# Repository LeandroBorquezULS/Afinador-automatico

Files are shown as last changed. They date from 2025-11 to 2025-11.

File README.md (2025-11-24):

## Afinador Automático

Este proyecto es un **afinador automático** desarrollado con el objetivo principal de ofrecer una herramienta de fácil acceso y uso para músicos, estudiantes, y cualquier persona interesada en afinar instrumentos musicales de manera precisa y rápida.

## Objetivo

El objetivo de este código es brindar un afinador automático que cualquiera pueda utilizar, permitiendo la afinación de instrumentos musicales de forma sencilla, intuitiva y rápida, sin necesidad de conocimientos técnicos avanzados. La interfaz y la lógica han sido diseñadas para minimizar la complejidad y maximizar la accesibilidad.

## ¿Cómo funciona?

El proyecto combina **Python** (95.5%) y **C++** (4.5%) para aprovechar las ventajas de ambos lenguajes:

- **Python:** Se encarga mayormente del procesamiento de señales de audio, la interfaz de usuario y la lógica principal del afinador.
- **C++:** Se utiliza para funciones de procesamiento de audio que requieren alta eficiencia y velocidad, como la detección rápida de frecuencia fundamental.

El afinador recibe una señal de audio (por ejemplo, de un micrófono), procesa la señal para detectar la frecuencia fundamental con algoritmos avanzados, y muestra al usuario la nota detectada y qué tan cerca está de la afinación perfecta.

## Características principales

- **Fácil de usar:** Interfaz accesible y minimalista.
- **Automático:** No requiere ajustes manuales por parte del usuario.
- **Precisión:** Algoritmos robustos de análisis de frecuencia.
- **Multiplataforma:** Pensado para funcionar en diferentes sistemas operativos.
- **Código abierto:** Puedes revisar, modificar y mejorar el código libremente.

## Tecnologías utilizadas

- **Python**: Librerías para procesamiento de audio como `numpy`, `scipy`, y `sounddevice` o `pyaudio`.
- **C++**: Módulos optimizados integrados sobre Python para análisis eficiente de la señal.

## Instalación y uso

1. Clona/Descargar este repositorio:
2. Instala las librerias requeridas.
3. Ejecuta el script principal que se encuentra en "main" siguiendo las instrucciones del repositorio.

## Materiales
(estos son los materiales esenciales para su funcionamiento)
- Motor Paso a Paso 28BYJ-48, 5v
- Driver ULN2003
- ESP32 D1 mini

## Contribuciones

¡Cualquier mejora, sugerencia o reporte es bienvenido! Este proyecto busca crecer como una herramienta comunitaria de acceso abierto.

---

**Hecho por [Leandro Borquez-Cristián Contreras-Maximiliano Molina-Jose Barraza-Maximiliano Oyarse-Piero Araya]**
- Bajo el contexto de la aplicación de Series de Fourier, en el marco del ramo Matemáticas IV, impartido por el Doctor Eric Roberto Jeltsch Figueroa en la Universidad de La Serena.
- Proyecto enfocado en el acceso universal a herramientas musicales inteligentes.

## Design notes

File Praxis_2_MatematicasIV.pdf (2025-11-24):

# Afinador Automatico de Instrumentos de Cuerda ´

Leandro Borquez, Piero Araya, Cristian Contreras, Maximiliano Oyarce, Maximiliano Molina, Jos ´ | e Barraza ´
Universidad de La Serena Ingeniería en Computacion´
Abstract—Este documento presenta el diseno e implementaci ˜ | on´
de un afinador automatico para instrumentos de cuerda. El ´ sistema utiliza analisis espectral mediante series de Fourier ´ para detectar la frecuencia fundamental de cada cuerda y un
sistema mecatronico para ajustar autom ´ | aticamente la tensi ´ | on. Se ´
describe el modelado matematico, la implementaci ´ | on hardware ´
con Arduino/ESP32, y los algoritmos de procesamiento digital de senales. Los resultados demuestran la efectividad del sistema ˜ para afinar guitarras con precision comparable a afinadores ´ comerciales.
Index Terms—Afinador automatico, series de Fourier, proce- ´
samiento digital de senales, Arduino, control autom ˜ | atico, STEM. ´
I. INTRODUCCION´
A. Problema desencadenante

La afinacion manual de instrumentos de cuerda requiere ´ entrenamiento auditivo y puede ser imprecisa para musicos ´ principiantes. Ademas, en entornos profesionales se requiere ´
rapidez y precision. Un sistema autom ´ | atico resolver ´ | ía estos
problemas proporcionando afinacion precisa independiente- ´ mente de la habilidad del usuario.
B. Limitaciones del afinado manual

El afinado manual para los instrumentos de cuerda es la manera mas usual al momento de afinar un instrumento de ´ cuerda como lo sería una guitarra, pero este metodo tiene ´ varios inconvenientes tales como la falta de experiencia, la falta de exactitud ya sea por problemas auditivos o por lo mismo de la falta de experiencia musical, un instrumento de cuerda como lo es la guitarra no estaría afinada a la nota exacta y tambien se pueden producir ciertos inconvenientes ´ al momento de estar afinado, como lo es que se rompa una cuerda por estar demasiado tensa y ademas aunque se afine ´ el instrumento hay factores externos que hacen que varíe la afinacion a lo largo del tiempo por lo que se debe de ´ comprobar la afinacion peri ´ odicamente. ´

C. Propuesta

Entonces como equipo se decidio por desarrollar un sistema ´
automatico para la afinaci ´ | on de la mayor ´ | ía de instrumentos de
cuerda, con la capacidad de que se acople a la mayoría de clavijeros y que pueda ajustar automaticamente las clavijas ´
para la afinacion de estos instrumentos. Adem ´ | as, el proyecto ´
busca ser una solucion de bajo costo y accesible, priorizando ´
componentes economicos y un dise ´ | no simple que permita ˜
que cualquier musico, tanto principiante como experimentado, ´ pueda utilizarlo sin necesidad de equipos profesionales.

II. OBJETIVOS
A. Objetivo General
Disenar e implementar un sistema autom ˜ | atico para afinar ´
instrumentos de cuerda que combine procesamiento digital de
senales y control mecatr ˜ | onico. ´
B. Objetivos Específicos
- Aplicar series de Fourier para deteccion de frecuencia ´ fundamental en senales de audio ˜
- Disenar el sistema mecatr ˜ | onico para ajuste autom ´ | atico de ´
clavijas
- Implementar algoritmos de control PID para el ajuste fino de tension´
- Validar el sistema experimentalmente comparando con afinadores comerciales o aplicaciones moviles para afinar ´ instrumentos
- Desarrollar habilidades STEM integradas en el equipo

III. MARCO TEORICO ´

A. Teoría Musical y Afinacion´
En el sistema occidental el sonido musical se organiza en 12 alturas por octava. Frecuencias estandar (A4 = 440Hz) para ´ la nota La en la cuarta octava en la afinacion moderna. Los ´ intervalos se miden por ”cents”, un semitono son 100 cents. En la musica el sonido tiene 4 cualidades las cuales son ´
- Altura, cualidad que determina si un sonido es agudo o grave
- Duracion´ tiempo en el que se mantienen las vibraciones producidas por el sonido
- Intensidad la diferencia entre un sonido suave y un sonido fuerte
- Timbre, cualidad que depende de los armonicos y de la ´ intensidad de estos
B. Afinadores comerciales y profesionales
Un afinador es una herramienta electronica con la capacidad ´ de detectar las vibraciones del sonido de un instrumento y muestra si se debe de ajustar la nota, para que el instrumento
este afinado, este es el m ´ | etodo m ´ | as r ´ | apido y efectivo para ´
lograr una afinacion precisa, pero no siempre es accesible ´ un afinador de alta calidad a un bajo precio. Afinadores por sistema
- Afinador Estandar ´ Afinadores usados por la mayoría, que solo detectan las notas específicas de la afinacion´ predeterminada de un instrumento.
- Afinador Cromatico ´ Estos detectan las 12 notas de la escala musical independientemente del instrumento, usado por profesionales por su versatilidad y exactitud.

- Diapason´ | Produce una nota de referencia inmutable
generalmente la de 440 Hz, es el metodo m ´ | as cl ´ | asico ´
para afinar un instrumento.
Afinadores por formato

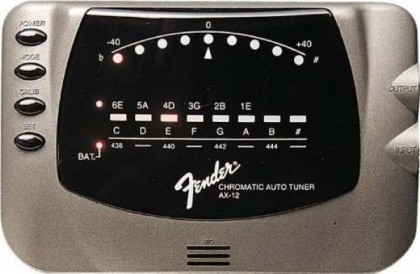
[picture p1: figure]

Fig. 1: Afinador Cromatico ´

Variaciones de los distintos afinadores
- Afinador de Pinza Estos se ajustan directamente al instrumento, leen las vibraciones directamente, lo que garantiza una afinacion precisa en ambientes ruidosos, ´
estos se ajustan a la clavijera o al mastil de un viol ´ | ín.
- Compacto Estos afinadores son para llevarlos en el bolsillo ideales para viajar con ellos, generalmente son del tipo cromatico ´ , con una entrada jack para guitarras electricas o bajos. ´
- Afinador de pedal Para guitarras y bajos electricos donde ´ se usa el pedal de efectos, permiten afinar directamente mientras se esta tocando, pudiendo activarlos y desacti- ´ varlos a voluntad.

IV. PROCESAMIENTO DIGITAL DE SENALES ˜

1) Series de Fourier:

f(x) = a0
2

+

X∞

n=1

(an cos(nπ
L
x) + bn sin(nπ
L
x)) | (1)
2) Transformada Rapida de Fourier (FFT): ´ | Algoritmo para
calculo eficiente del espectro de frecuencia con la FFT, de- ´ scomponiendo la senal de audio de la cuerda en sus compo- ˜ nentes de frecuencia, donde el pico de mayor amplitud es la frecuencia fundamental.
A. Percepcion del pitch ´

La frecuencia fundamental y armonicos, la frecuencia fun- ´ damental define la altura percibida de un sonido lo que sería su pitch, mientras que los armonicos son las diferentes ”distan- ´ cias” que se tienen para recorrer para cada nota, haciendo que
los armonicos sean los m ´ | ultiplos enteros de esta frecuencia ´
fundamental.
Por lo que se puede concluir que un sonido consta de su
frecuencia fundamental, seguido de los armonicos m ´ | ultiplos ´
de esta frecuencia fundamental.
B. Descomposicion espectral ´

Por medio de la FFT se va a descomponer el sonido de las cuerdas, mostrando su frecuencia fundamental y permitiendo compararla con la frecuencia de referencia de 440Hz.

C. Teoría de Control
Control PID para el sistema de ajuste de tension donde ´ el controlador automatico iterativo ajusta el motor en bucle ´ cerrado. Que calcula los pasos en funcion del error ´
u(t) = min
nmax

|cents|

cents − por − paso
(2)

El controlador proporcional-integral-derivativo o PID, se en-
cargara de decidir cu ´ | anto y en qu ´ | e sentido se debe de mover el ´
motor a paso a paso que tensa o afloja la cuerda y así alcanzar la frecuencia deseada para cada cuerda. Entonces la mision de ´
este controlador es la de traducir el error instantaneo en ´ | cents
en una cantidad entera de pasos del motor, lo que permite que:
1) Corrija la desviacion en un instante ´
2) Que no sobrepase los límites del clavijero.
V. FUNDAMENTOS TEORICOS ´
A. ¿Como se debe afinar una guitarra? ´
El estandar para la afinaci ´ | on de guitarras es de (mi-la-re- ´
sol-si-mi) donde la sexta cuerda corresponde a la nota Mi (E), la quinta en La (A), la cuarta en Re (D), la tercera en Sol (G), la segunda en Si (B) y la primera cuerda afinada tambien en ´ Mi (E). La frecuencia referencial mas com ´ un es la de 440Hz. ´
B. Temperamento igual
El temperamento igual divide la octava en 12 partes iguales, a los que se les conoce como semitonos. Un semitono sería el
espacio mas peque ´ | no entre las notas en el sistema occidental, ˜
donde cada semitono va a medir la distancia de 12√
2. Esta
distancia mínima permite calcular la frecuencia de todas las
notas con esta formula ´ | (

12√
2)n ∗ f, donde f sera la frecuencia ´ de la nota de referencia y n es el numero de semitonos que ´ se quiere subir a partir de la nota de referencia.
C. Cuerdas vibrantes
En una cuerda su vibracion ser ´ a una onda cuyo sonido ´ producido sera una frecuencia constante, las cuerdas vibrantes ´ son la base de los instrumentos de cuerda como la guitarra, el violín o el piano. Donde su funcionamiento sigue las leyes de Mersenne, que se podría resumir en estos tres principios
- Mas corta la cuerda, m ´ | as alta es la frecuencia del modo ´
fundamental o una cuerda mas corta produce una nota ´ mas aguda. ´
- Mas grande la tensi ´ | on, m ´ | as alta es la frecuencia fun- ´
damental o una cuerda mas tensa vibra m ´ | as r ´ | apido, ´
produciendo una nota mas aguda. ´
- Mas liviana la cuerda, m ´ | as alta es la frecuencia del modo ´
fundamental o entre mas liviana una cuerda m ´ | as aguda ´
es la nota que produce.
VI. DISENO DEL ˜ | SISTEMA
A. Arquitectura General
El sistema debe de
1) Capturar el audio del microfono ´
2) Procesar la senal y usar la FFT para encontrar la ˜ frecuencia fundamental

3) Comparar la frecuencia medida con la frecuencia objetivo de cada cuerda, con la tabla de frecuencia del temperamento igual
4) Controlar los motores para aumentar o disminuir la tension´
5) Iterar Repetir el proceso hasta que el instrumento esté afinado

Diagrama de la secuencia

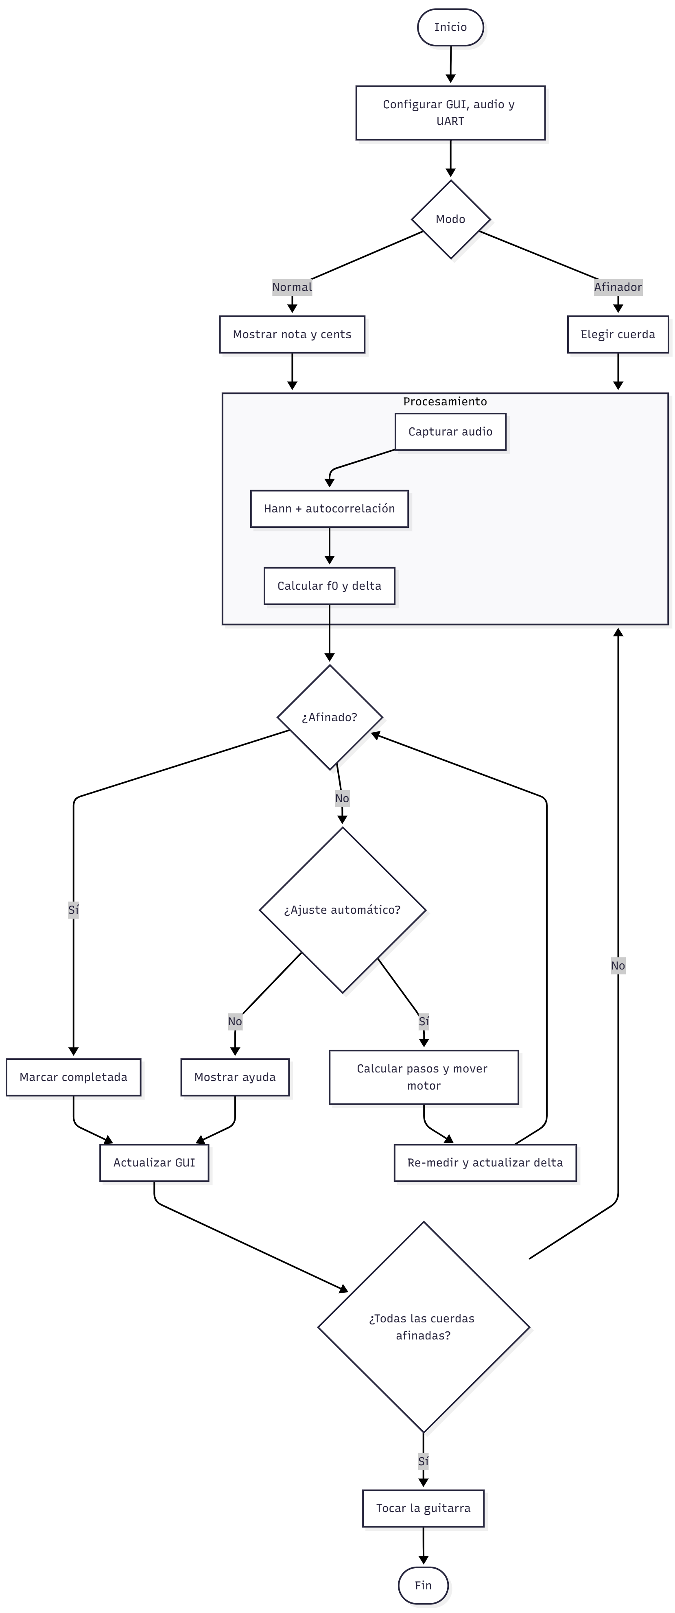
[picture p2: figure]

Fig. 2: Diagrama DFD

B. Modelado Matematico REVISAR ´
1) Modelo de la Cuerda: Ecuacion de onda para cuerdas ´ vibrantes:
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
2) Relacion Tensi ´ | on-Frecuencia: ´ | Ley de Mersenne. Esta
funcion convertir ´ | a el error ´ | δ en accion mec ´ | anica sin la ´
necesidad de medir el tiempo T, L, µ:

f =

1
2L

s
T
µ

(4)

La solucion de estas ecuaciones permite convertir el error ´ calculado en cents, en un numero discreto de pasos para el ´ motor calculando experimentalmente la ganancia.

VII. ESTADO DEL ARTE
Realizando un analisis de los afinadores digitales existentes, ´ así como de las aplicaciones moviles actuales, se observa que ´ el mercado ofrece una amplia variedad de herramientas para la
afinacion. Sin embargo, la gran mayor ´ | | ía de estos dispositivos
aun requiere que el usuario realice el ajuste manual del ´ instrumento. En contraste, los sistemas semiautomaticos y ´
automaticos de afinaci ´ | on representan solo una fracci ´ | on muy ´
pequena del mercado, convirti ˜ | endose en productos de nicho ´
debido a su alto costo, complejidad mecanica o falta de ´ accesibilidad.

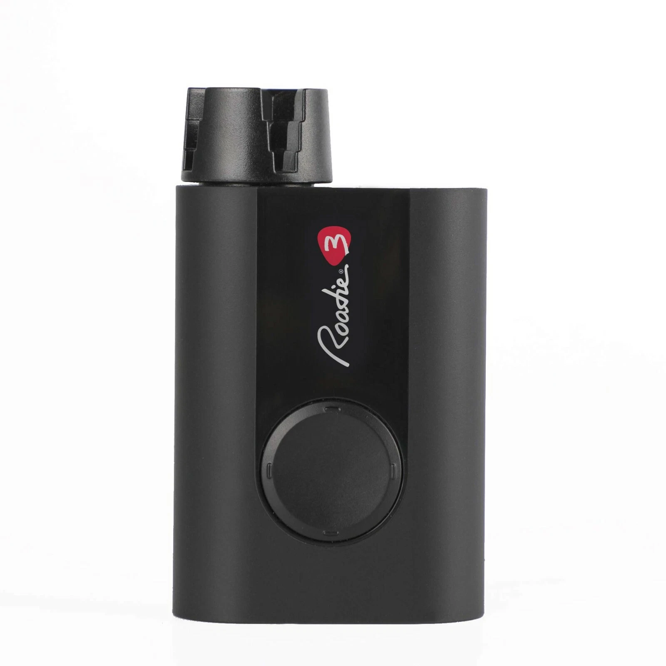
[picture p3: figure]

Fig. 3: Afinador automatico ´

Historicamente, el estudio de la afinaci ´ | on y del an ´ | alisis ´
de frecuencias comenzo a formalizarse a mediados del siglo ´ XX, cuando surgieron las primeras investigaciones en proce-
samiento digital de senales (DSP). Con la aparici ˜ | on de los ´
primeros computadores en la decada de 1960, se desarrollaron ´
las bases matematicas de la Transformada R ´ | apida de Fourier ´
(FFT), introducida por Cooley y Tukey en 1965, lo que per-
mitio analizar se ´ | nales musicales con mucha mayor eficiencia. ˜
Estas herramientas fueron inicialmente utilizadas para fines militares y de telecomunicaciones, como analisis espectral de ´ senales de radar, sonar y comunicaciones de radio. Con el ˜ tiempo, la tecnología migro hacia aplicaciones recreativas, ´ educativas y artísticas, impulsando su uso en el estudio del sonido y la musica. ´
Desde la decada de 1980, el procesamiento de audio digital ´
comenzo a integrarse en sintetizadores, afinadores electr ´ | onicos ´
de mano y equipos de grabacion profesional. A inicios de ´ los anos 2000, el avance de los microcontroladores y sen- ˜
sores mas econ ´ | omicos permiti ´ | o que proyectos acad ´ | emicos y ´
experimentales exploraran la afinacion autom ´ | atica mediante ´
motores de precision y algoritmos que detectan la frecuencia ´ fundamental de cuerdas en vibracion. Diversas investigaciones ´
han empleado tecnicas basadas en FFT, autocorrelaci ´ | on, filtros ´
digitales y analisis espectral avanzado para lograr una esti- ´ macion precisa del tono musical. ´
En el ambito acad ´ | emico, se han desarrollado numerosos ´
trabajos enfocados en la afinacion digital y el control autom- ´ atizado de instrumentos musicales. Algunos estudios abordan algoritmos de deteccion de pitch robustos al ruido, mientras ´ que otros se concentran en la construccion de sistemas elec- ´ tromecanicos capaces de ajustar tensiones de cuerdas. Incluso ´

existen proyectos que implementan sistemas completos de
afinacion autom ´ | atica, dise ´ | nando actuadores controlados por ˜
microcontroladores para manipular clavijas de instrumentos de cuerda de manera autonoma. ´

Con el crecimiento de la computacion embebida y el ´ acceso a plataformas como Arduino, ESP32 y Raspberry Pi, la investigacion reciente se ha orientado hacia sistemas ´
mas compactos, energ ´ | eticamente eficientes y accesibles para ´
el publico general. Esto ha permitido desarrollar prototipos ´
economicos y port ´ | atiles con capacidades que antes solo se ´
encontraban en dispositivos profesionales de alto costo.

En conclusion, aunque existe un cuerpo importante de ´
estudios y prototipos relacionados con la afinacion autom ´ | atica, ´
la mayoría no se ha traducido en productos comerciales ampliamente accesibles. Esto refuerza la necesidad de soluciones de bajo costo, simples de usar y capaces de adaptarse a distintos instrumentos, especialmente en contextos educativos, recreativos y artísticos.

VIII. IMPLEMENTACION´

A. Hardware
- Microcontrolador: Arduino/ESP32
- Sensor: Microfono ´
- Actuadores: motores paso a paso
- Mecanismo: Adaptador para clavijas

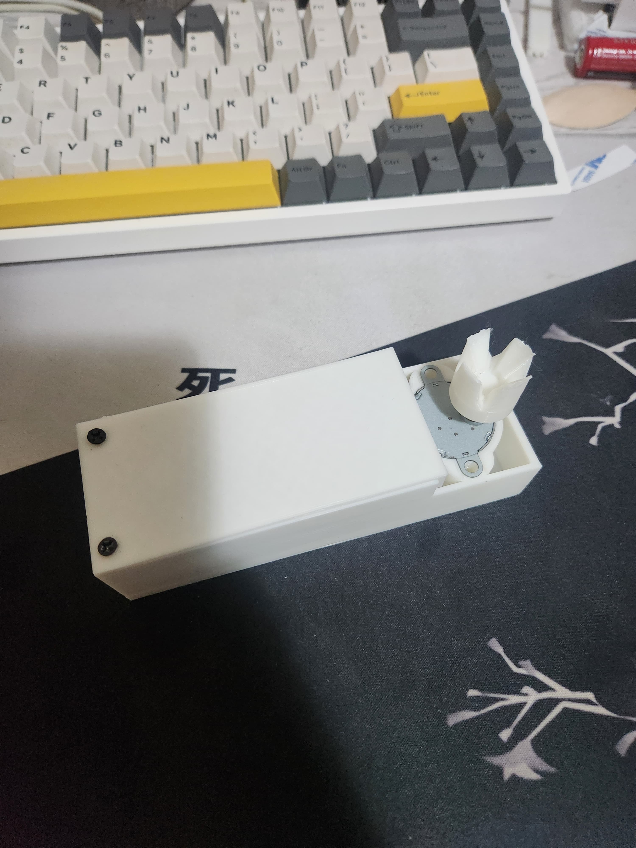
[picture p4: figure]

Fig. 4: Afinador

B. Software

TABLE I: Librerías de Python utilizadas y su funcion´

Librería | | | Funcion´
Calculo num ´ | erico eficiente, manejo de matrices y operaciones matem ´ | aticas avanzadas. heightsounddevice ´ | Captura y reproduccion de audio directa- ´
Creacion de interfaces gr ´ | aficas en Python. heighttkinter.ttk, messagebox ´ | ttk: widgets modernos y estilizados; mes-
Cola doble eficiente, util para almacenar historial o aplicar suavizado temporal. heightmath.log2 ´ | Calculo de logaritmos base 2, ´ | util en proce- ´
Creacion de figuras cient ´ | íficas para graficos personalizados. heightFigureCanvasTkAgg ´ | Integracion de gr ´ | aficos Matplotlib dentro de ´
Comunicacion con dispositivos mediante puerto serie (por ejemplo, ESP32). heightserial.tools.list ´ | ports | Listado y deteccion autom ´ | atica de puertos ´
Manejo de tiempos, pausas y temporizadores. heightthreading | Ejecucion de tareas en paralelo mediante ´

IX. METODOLOGÍA EXPERIMENTAL

A. Configuracion de Pruebas ´

Procedimiento para validacion del sistema, instrumentos de ´
medicion, criterios de evaluaci ´ | on. ´
B. Metricas ´
- Precision en cents ´
- Tiempo de afinacion´
- Consistencia entre cuerdas
X. CONCLUSIONES
El desarrollo de este afinador automatico demostr ´ | o que es ´
posible construir un sistema funcional, economico y accesible ´ capaz de afinar instrumentos de cuerda sin intervencion man- ´ ual del usuario. Mediante el uso de analisis espectral basado ´
en FFT, un control mecatronico simple y materiales f ´ | aciles de ´
obtener, se logro implementar un prototipo que identifica la ´ frecuencia fundamental de las cuerdas y ajusta su tension de ´ manera autonoma. ´
El proyecto permitio integrar conocimientos de teor ´ | ía mu-
sical, procesamiento digital de senales y control autom ˜ | atico, ´
mostrando que tecnologías actuales como Arduino o ESP32
son suficientes para acercar soluciones de afinacion autom ´ | atica ´
a estudiantes, musicos principiantes y usuarios sin experiencia ´
tecnica. Adem ´ | as, el dise ´ | no modular facilita futuras mejoras, ˜
como aumentar la precision del algoritmo, optimizar el sistema ´ de sujecion a las clavijas o incorporar diferentes modos de ´ afinacion. ´
| En conclusion, el afinador casero desarrollado cumple con ´
los objetivos planteados, ofreciendo una alternativa funcional y de bajo costo frente a los afinadores automaticos comerciales, ´ y demostrando que la combinacion de hardware accesible y al- ´ goritmos DSP bien implementados permite obtener resultados satisfactorios en aplicaciones musicales reales.

AGRADECIMIENTOS

REFERENCES

[1] J. O. Smith, Mathematics of the Discrete Fourier Transform, 2020.
[2] J. G. Proakis y D. G. Manolakis, Digital Signal Processing, Prentice Hall, 2007.
[3] B. Pardo y W. P. Birmingham, Achieving Robust Performance in an Automatic Guitar Tuner, 2004.
[4] Documentacion oficial de Arduino, https://www.arduino.cc/ ´
[5] Artículo | sobre | afinadores, | https://goldmusiccenter.com/
post-todo-sobre-afinadores-15#:∼:text=Un%20afinador%20es% 20un%20dispositivo,de%20lograr%20una%20afinaci%C3%B3n% 20impecable. (https://goldmusiccenter.com/post-todo-sobre-afinadores-15)
[6] Detlev Andre Chafchalaf Pe ´ | | na http://biblioteca.usac.edu.gt/tesis/08/ ˜
08 0342 EO.pdf#:∼:text=Se%20incluye%20una%20breve%20teor% C3%ADa%20musical%20para,tarjeta%20de%20sonido%20de%20la% 20computadora%2C%20que (http://biblioteca.usac.edu.gt/tesis/08/08_0342_EO.pdf)
[7] Mohammad Mainul Hasan, Desarrollo de un afinador de guitarra
acustica y una interfaz gr ´ | | afica de usuario (GUI) utilizando MAT- ´
LAB https://journals2.ums.ac.id/index.php/arstech/article/view/1185#:∼:text=Abstract,high%20sensitivity%20of%20traditional%20ones. (https://journals2.ums.ac.id/index.php/arstech/article/view/1185)
[8] Portelli, L. (2003). Universidad del Valle de Guatemala. https://repositorio.uvg.edu.gt/handle/123456789/489

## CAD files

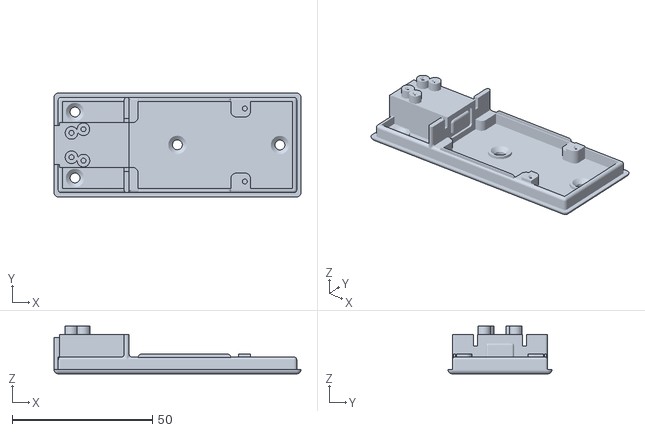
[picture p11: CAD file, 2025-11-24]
Modelo _3D/base_stepper_ESP32_D1.stl
88.0 x 37.0 x 17.0

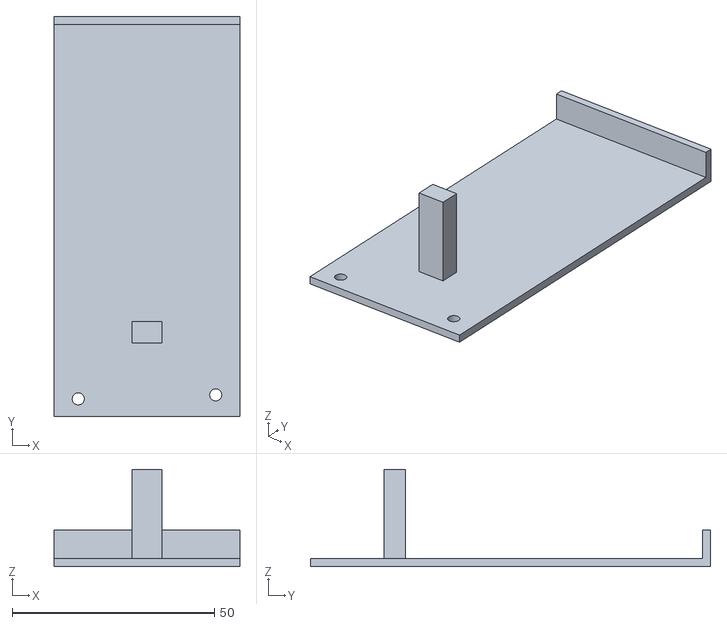
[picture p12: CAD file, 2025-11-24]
Modelo _3D/base_tapa.stl
46.0 x 99.0 x 24.0

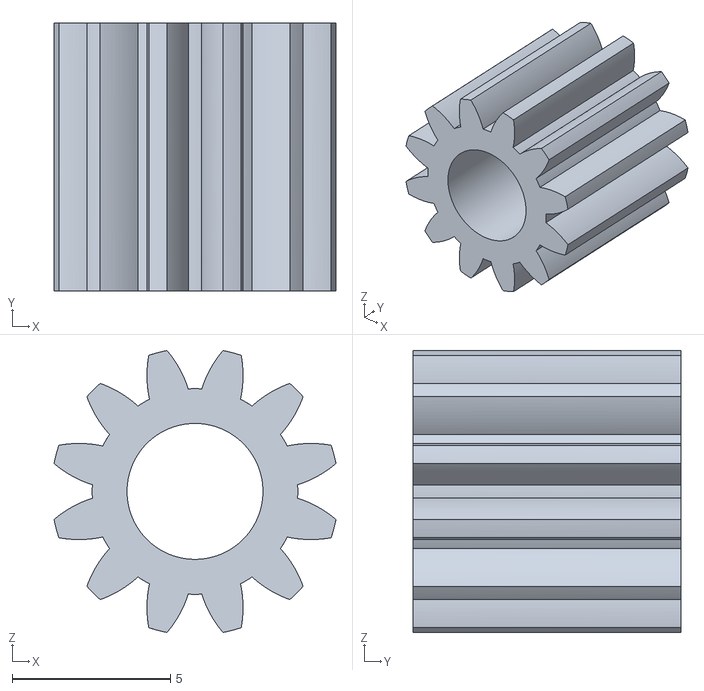
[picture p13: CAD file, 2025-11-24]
Modelo _3D/3_engranaje_ajuste.stl
8.92 x 8.46 x 8.92

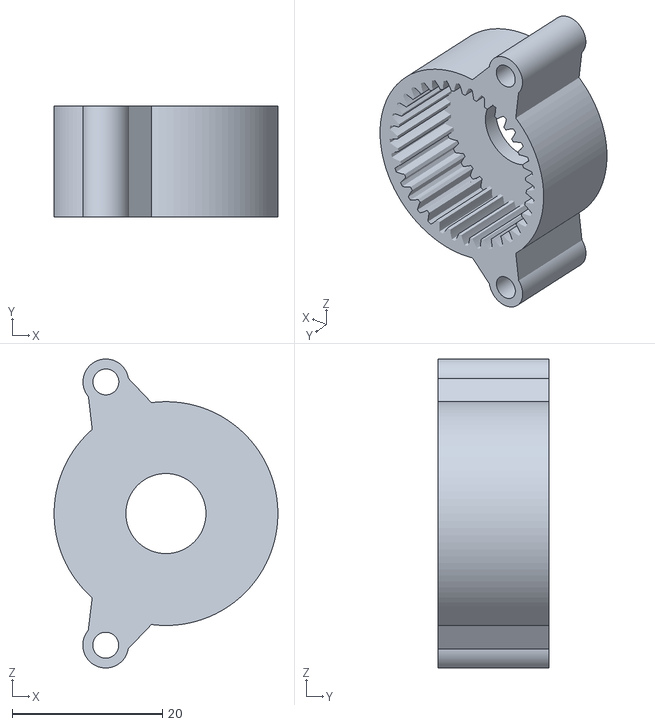
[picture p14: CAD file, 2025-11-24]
Modelo _3D/engranaje_base.stl
29.8 x 14.7 x 41.1

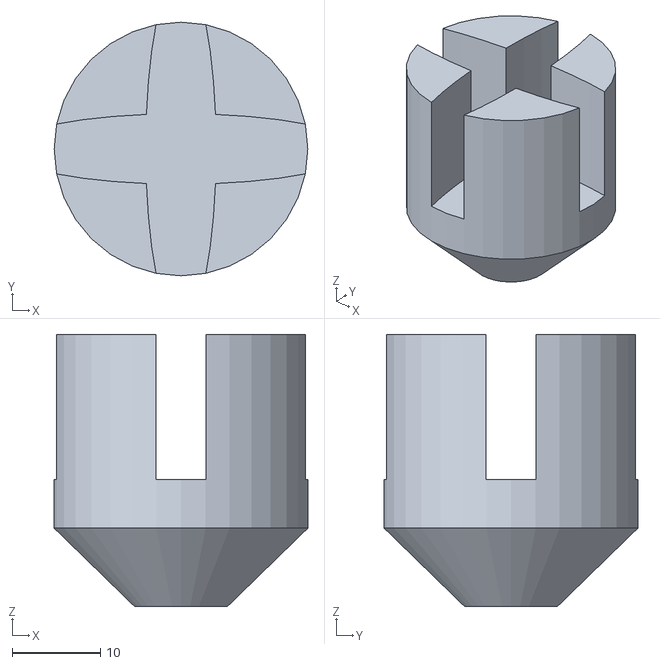
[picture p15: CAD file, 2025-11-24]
Modelo _3D/ajuste_exagonal_2_v3.stl
28.8 x 28.8 x 30.9

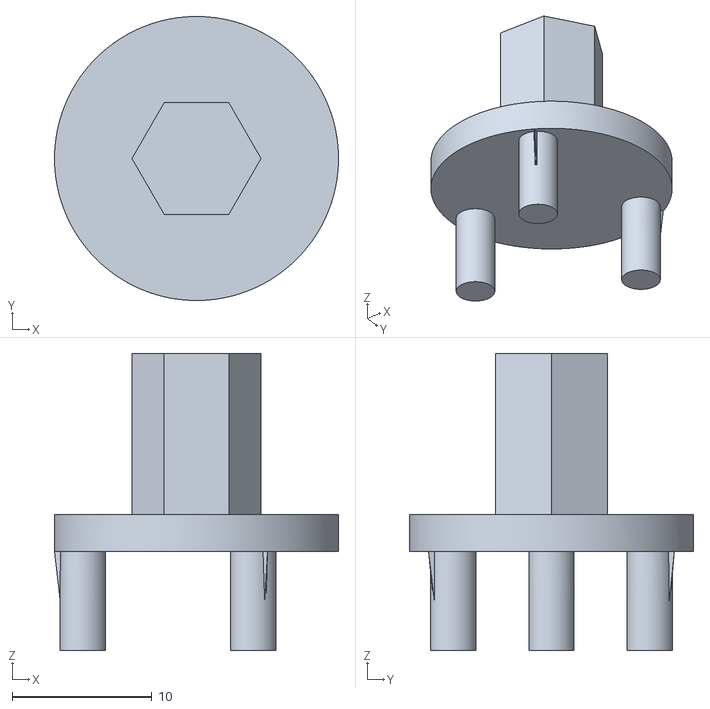
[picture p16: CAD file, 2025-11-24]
Modelo _3D/ajuste_exagonal_parte1.stl
20.3 x 20.3 x 21.3

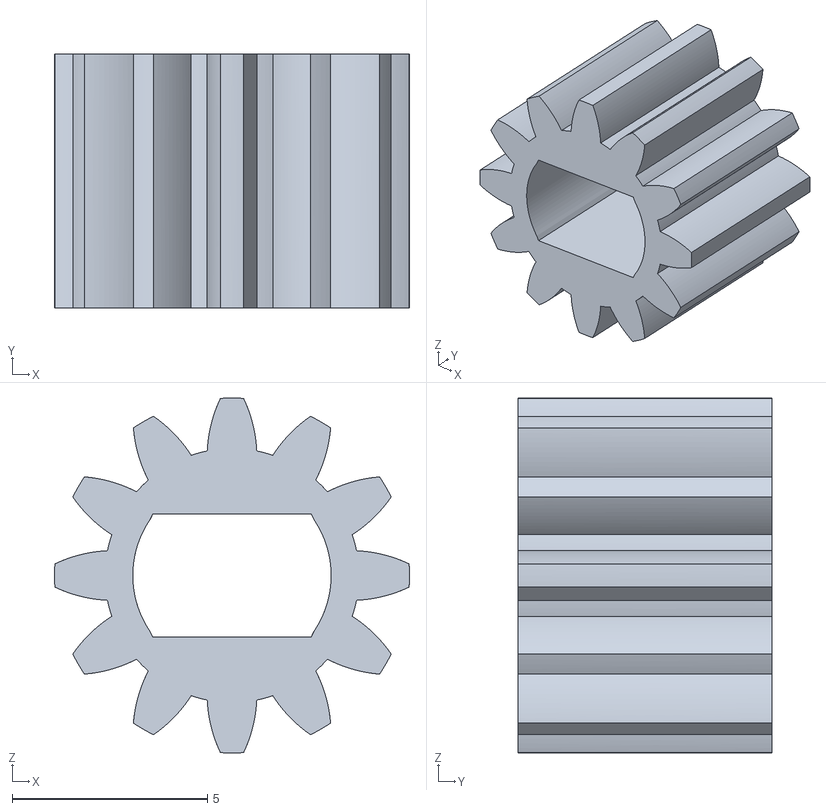
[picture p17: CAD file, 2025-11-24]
Modelo _3D/engranaje_motor.stl
9.09 x 6.50 x 9.09

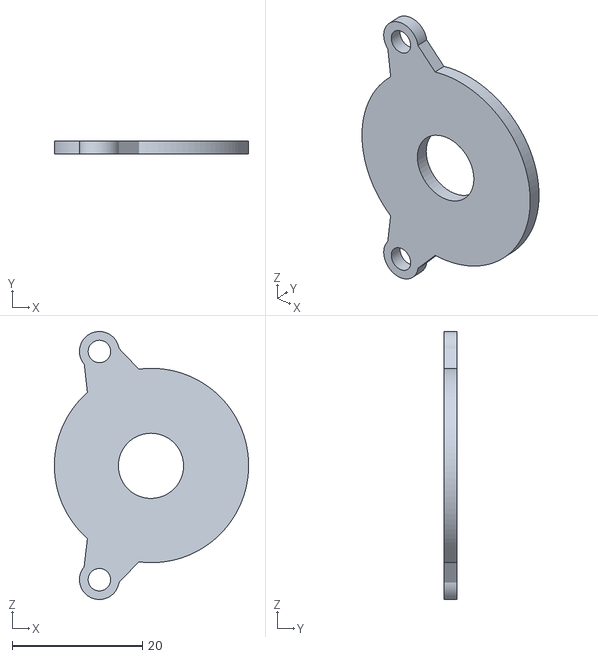
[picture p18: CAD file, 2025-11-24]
Modelo _3D/engranaje_tapa.stl
29.8 x 2.00 x 41.1

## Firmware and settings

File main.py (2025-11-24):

import numpy as np           # Librería para cálculos numéricos y manejo eficiente de arreglos/matrices.
import sounddevice as sd     # Permite grabar y reproducir audio desde Python usando dispositivos de sonido.
from collections import deque # Estructura de datos tipo cola doblemente terminada, útil para almacenar historial.
from math import log2         # Función matemática para logaritmo base 2.
import serial                 # Comunicación serie (puertos COM) para interactuar con hardware externo (ej. ESP32).
import serial.tools.list_ports # Herramientas para listar los puertos serie disponibles.
import time                   # Funciones para manejo de tiempo y temporizadores.
import threading              # Permite ejecutar tareas en paralelo (hilos) dentro del programa.

# ---------- PARAMETROS ---------- (ajusta según necesidad)
FS = 44100
CHUNK = 4096
UPDATE_MS = 120
SMOOTH_N = 5
A4_FREQ = 440.0

ORANGE_CENTS = 20
GREEN_CENTS = 5
STABLE_MS_REQUIRED = 500         # ahora 500 ms (0.5 s) de estabilidad requerida
STABLE_CENTS_THRESHOLD = 3.0     # tolerancia en cents para considerar "misma frecuencia" (ajustable)

SOLFEGE = ['Do', 'Do#', 'Re', 'Re#', 'Mi', 'Fa', 'Fa#', 'Sol', 'Sol#', 'La', 'La#', 'Si']

GUITAR_STRINGS = {
    "6 - Mi (E2)": 82.4069,
    "5 - La (A2)": 110.0,
    "4 - Re (D3)": 146.832,
    "3 - Sol (G3)": 195.998,
    "2 - Si (B3)": 246.942,
    "1 - Mi (E4)": 329.628
}

# ---------- SERIAL helpers ----------
def find_esp32_port():
    ports = list(serial.tools.list_ports.comports())
    for p in ports:
        desc = (p.description or "").upper()
        if "USB" in desc or "ESP32" in desc or "CP210" in desc or "CH340" in desc:
            return p.device
    return None

def open_serial(port, baud=115200, timeout=1):
    try:
        ser = serial.Serial(port, baud, timeout=timeout)
        time.sleep(2)
        ser.flushInput()
        return ser
    except Exception as e:
        print("Error abriendo puerto serial:", e)
        return None

# ---------- FRECUENCIA / NOTA ----------
def freq_to_note_name(freq):
    if freq <= 0 or not np.isfinite(freq):
        return None, None, None
    n = 12 * log2(freq / A4_FREQ)
    semitone = int(round(n))
    note_index = (semitone + 9) % 12
    octave = 4 + ((semitone + 9) // 12)
    note_name = SOLFEGE[note_index]
    note_freq = A4_FREQ * (2 ** (semitone / 12))
    return note_name, octave, note_freq

def cents_difference(freq, target_freq):
    if freq <= 0 or target_freq <= 0:
        return None
    return 1200 * log2(freq / target_freq)

def get_freq_autocorr(data):
    data = np.nan_to_num(np.asarray(data, dtype=float))
    if np.allclose(data, 0):
        return 0.0
    data -= np.mean(data)
    window = np.hanning(len(data))
    data_w = data * window
    corr = np.correlate(data_w, data_w, mode='full')
    corr = corr[len(corr)//2:]
    d = np.diff(corr)
    try:
        start = np.where(d > 0)[0][0]
    except IndexError:
        return 0.0
    peak = np.argmax(corr[start:]) + start
    if peak == 0:
        return 0.0
    return FS / peak

# ---------- MOTOR CONTROLLER (protocolo simple) ----------
class MotorController:
    """
    Protocolo: send "<dir><steps>\n" where dir is '+' (tensionar) or '-' (aflojar).
    ESP32 replies "DONE\n" when finished. Send "S\n" to stop/abort.
    """
    def __init__(self, ser):
        self.ser = ser
        self.lock = threading.Lock()
        self.last_response = None
        self._running = False
        if ser:
            self._running = True
            t = threading.Thread(target=self._reader_thread, daemon=True)
            t.start()

    def _reader_thread(self):
        while self._running and self.ser and self.ser.is_open:
            try:
                line = self.ser.readline().decode('utf-8', errors='ignore').strip()
                if line:
                    with self.lock:
                        self.last_response = line
            except Exception:
                pass
            time.sleep(0.01)

    def send_move(self, direction, steps, timeout=10.0):
        if not self.ser or not self.ser.is_open:
            return False
        cmd = f"{direction}{int(steps*5)}\n"
        with self.lock:
            self.last_response = None
        try:
            self.ser.write(cmd.encode('utf-8'))
        except Exception:
            return False
        t0 = time.time()
        while time.time() - t0 < timeout:
            with self.lock:
                if self.last_response is not None:
                    if "DONE" in self.last_response:
                        return True
            time.sleep(0.02)
        return False

    def stop(self):
        if self.ser and self.ser.is_open:
            try:
                self.ser.write(b"S\n")
            except Exception:
                pass

    def close(self):
        self._running = False
        if self.ser:
            try:
                self.ser.close()
            except Exception:
                pass


# Lanzar la interfaz gráfica desde el archivo interfaz.py
if __name__ == "__main__":
    from interfaz import TunerApp
    import tkinter as tk
    root = tk.Tk()
    app = TunerApp(root)
    root.mainloop()

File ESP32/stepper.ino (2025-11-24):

// Pines del ESP32 conectados al ULN2003
const int IN1 = 14;
const int IN2 = 27;
const int IN3 = 26;
const int IN4 = 25;

// Tiempo entre pasos (ms). Si el motor vibra, súbelo.
int stepDelay = 5;

// Secuencia estándar para 28BYJ-48
void stepMotor(int stepIndex) {
  switch (stepIndex) {
    case 0: digitalWrite(IN1,1); digitalWrite(IN2,1); digitalWrite(IN3,0); digitalWrite(IN4,0); break;
    case 1: digitalWrite(IN1,0); digitalWrite(IN2,1); digitalWrite(IN3,1); digitalWrite(IN4,0); break;
    case 2: digitalWrite(IN1,0); digitalWrite(IN2,0); digitalWrite(IN3,1); digitalWrite(IN4,1); break;
    case 3: digitalWrite(IN1,1); digitalWrite(IN2,0); digitalWrite(IN3,0); digitalWrite(IN4,1); break;
  }
}

void moverAdelante(int pasos) {
  for (int i = 0; i < pasos; i++) {
    for (int j = 0; j < 4; j++){
      stepMotor(j);
      delay(stepDelay);
    }
    delay(stepDelay);
  }
}

void moverAtras(int pasos) {
  for (int i = 0; i < pasos; i++) {
    for (int j = 3; j >= 0; j--){
      stepMotor(j);
      delay(stepDelay);
    }
    delay(stepDelay);
  }
}

void setup() {
  Serial.begin(115200);
  pinMode(IN1, OUTPUT);
  pinMode(IN2, OUTPUT);
  pinMode(IN3, OUTPUT);
  pinMode(IN4, OUTPUT);

  Serial.println("Listo. Comandos: f100 = 100 pasos adelante, b200 = 200 pasos atrás.");
}

void loop() {
  if (Serial.available()) {
    String cmd = Serial.readStringUntil('\n');
    cmd.trim();

    if (cmd.length() < 2) return;

    char dir = cmd.charAt(0);
    int pasos = cmd.substring(1).toInt();

    if (dir == '+') moverAdelante(pasos);
    if (dir == '-') moverAtras(pasos);
    if (dir == 's') {
      digitalWrite(IN1,0);
      digitalWrite(IN2,0);
      digitalWrite(IN3,0);
      digitalWrite(IN4,0);
    }
  }
}

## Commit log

2025-11-17 Agregada función de afinador con stepper motor
2025-11-18 intento 1
    organizar de mejor manera el codigo
2025-11-22 Mejora_interfaz
    estoy mejorando la interfaz para que se sientas mas facil de comprender
2025-11-22 Codifo Funcional
    Funciona, hace lo que tiene que hcer
2025-11-22 describe que dice cada icono
2025-11-23 ojala que sea esto
2025-11-24 mejora de torque
2025-11-24 nombre de la carpeta
    [3_engranaje_ajuste.stl, ajuste_exagonal_2_v3.stl, ajuste_exagonal_parte1.stl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]
2025-11-24 actualizacion de leo
